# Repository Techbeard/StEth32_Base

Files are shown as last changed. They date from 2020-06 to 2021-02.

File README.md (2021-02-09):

# StEth32_Base

Das STEth32_Base ist ein auf STM32 Basiendes Ethernet Board. Es ist eine Fortführung des schon bestehenden [StEth32](https://github.com/Techbeard/StEth32). Dieses mal ist das Board allerdings darauf optimiert/ausgelegt in einm [Alu-Gehäuse](https://www.reichelt.de/profilgehaeuse-1455-l-120-x-103-x-31-mm-silber-1455l1202-p221363.html?&nbc=1)  eingesetzt zu werden. 

Um das Board möglichst vielseitig nutzen zu können sind auf dem Base Board alle unverwendeten Pins auf die Hinteren Vier Buchsenleisten geführt, wodurch Sie auf einem Erweiterungsboard für alles mögliche eingestezt werden können.

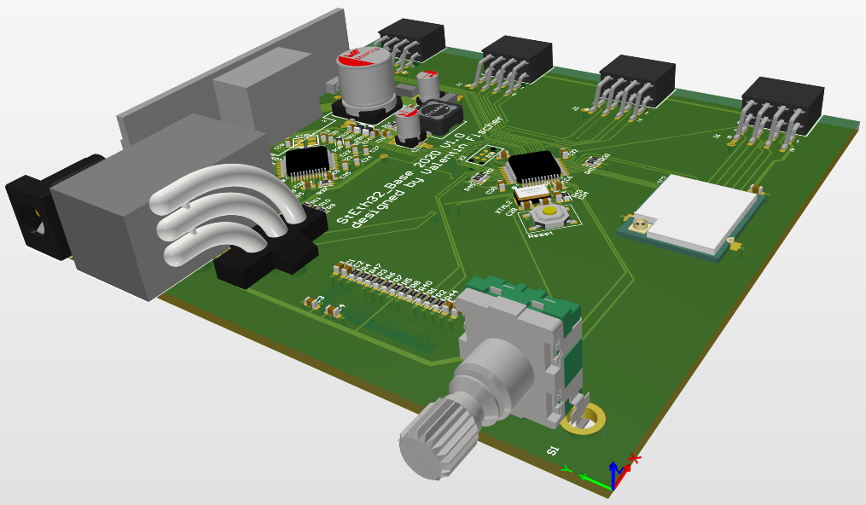
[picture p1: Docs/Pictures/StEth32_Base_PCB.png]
StEth32 Base Board


## Fetures auf dem Base Board

Eingangsspannung: 5 - 28 V

- [OLED](https://lcsc.com/product-detail/OLED-Displays-Modules_Shenzhen-Allvision-Tech-QG-2864KLBLG01_C90547.html)
- [Drehencoder](https://www.conrad.de/de/p/alps-stec11b02-encoder-5-v-dc-0-01-a-360-1-700696.html)
- Ethernet mit W5500
- 5.5x2.1 Hohlbuchse zur Stromversorgung
- POE Module zur Stromversorgung
- Footprint für [NRF24](https://lcsc.com/product-detail/Wireless-Modules_Chengdu-Ebyte-Elec-Tech-E01-ML01SP4_C97340.html)
- 2x Status LED

## Pinout

J3                                                                
| STM32 | Function | Pin | Pin | Function  | STM32 |
| :-----| :--- | :----- | :----- | :--- | :---- |
| | Vcc | **1**  | **2**  | Vcc | |  
| | TX3 | **3**  | **4**  | RX3 | | 
| | RX2 | **5**  | **6**  | TX2 | | 
| | TX1 | **7**  | **8**  | RX1 | |

J4
| STM32 | Function | Pin | Pin | Function  | STM32 |
| :-----| :--- | :----- | :----- | :--- | :---- |
| | SCL | **1**  | **2**  | SDA | |  
|  PB3  | | **3**  | **4**  |  USB/CAN  | PA12 | 
| | | **5**  | **6**  | | PB4 | 
| | 3,3V | **7**  | **8**  | GND | |

J5                                                          
| STM32 | Function | Pin | Pin | Function  | STM32 |
| :-----| :--- | :----- | :----- | :--- | :---- |
| | 3,3V | **1**  | **2**  | | PB8 |  
| PA15  | | **3**  | **4**  | RX1 | PB9 | 
| PB5 | | **5**  | **6**  | Reset | NRST | 
| | | **7**  | **8**  | GND | GND |

J6
| STM32 | Function | Pin | Pin | Function  | STM32 |
| :-----| :--- | :----- | :----- | :--- | :---- |
| | 3,3V | **1**  | **2**  | |  PA8 |  
| | CS | **3**  | **4**  | | PB1 | 
| | SCK | **5**  | **6**  | MOSI | PA3 | 
| | MISO | **7**  | **8**  | GND | |

## Intern verwendete Pins

### Ethernet SPI

Der Ethernet Chip W5500 hängt auf dem SPI2 des STM32:

    MOSI => PB15
    MISO => PB14
    SCK  => PB13
    CS   => PB12
    INT  => PA8

### Serial RS485

Der MAX485 hängt an den Pins für den Serial1 des STM32
 
    RX => PB11
    TX => PB10
    EN => PB1

### Staus Led

    LED => PC13 LOW aktiv

### MOSFET Ausgänge

    T1 => PB3
    T2 => PA15
    T3 => PB5
    T4 => PB4

# Einsatzzwecke / Erweiterungsboards

## Artnet2DMX

Das erste Erweiterungsboard verwandelt das Baseboard in einen Artnet to DMX Converter zu verwandeln. Es Werden die 3 Serielen Schnittstellen des STM32 zu RS4
85 gewandelt und über 3 XLR Buchsen ausgegeben. 

Die dazugehörige Software findest man hier:

https://github.com/LeoDJ/StEth32_Artnet2DMX

|||
|:--:|:--:|
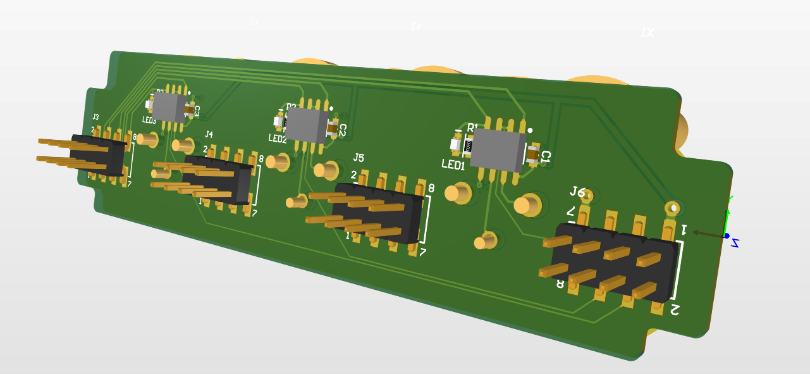
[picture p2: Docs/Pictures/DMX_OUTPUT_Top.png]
Rückseite des Erweiterungsboards
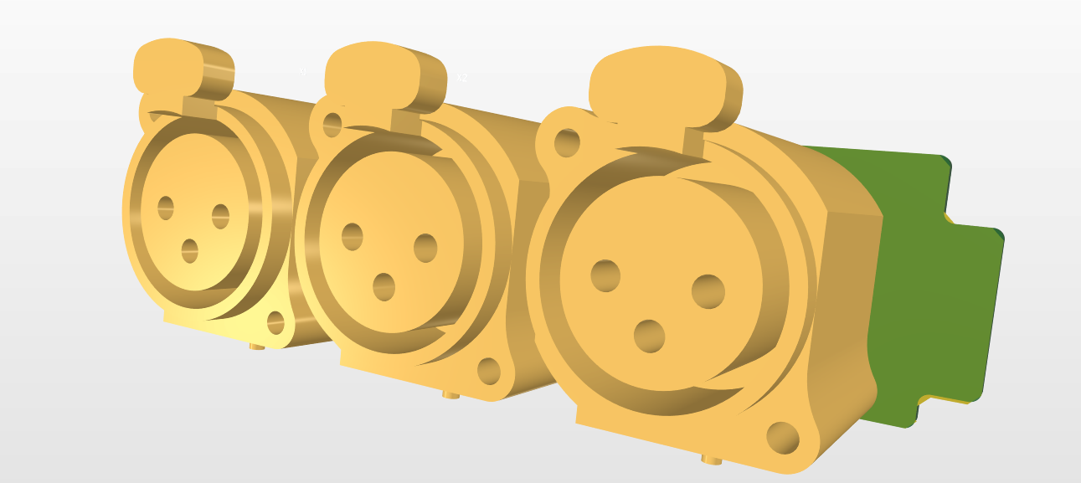
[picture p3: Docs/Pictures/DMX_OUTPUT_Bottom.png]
Vorderseite des Erweiterungsboards
|  | |
|*Rückseite des Erweiterungsboards*|*Vorderseite des Erweiterungsboards*|
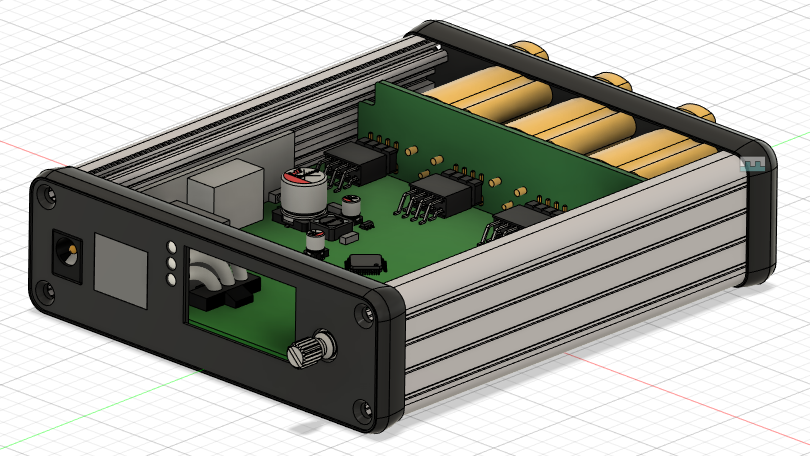
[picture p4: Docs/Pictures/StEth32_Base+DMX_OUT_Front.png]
StEth32
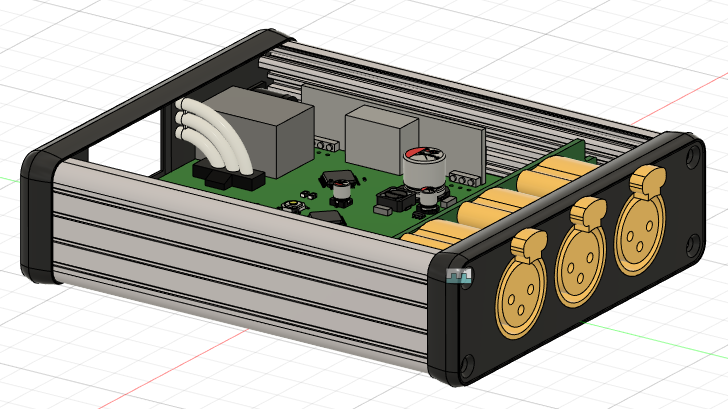
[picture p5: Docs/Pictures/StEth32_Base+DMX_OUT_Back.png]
StEth32
|  | |
|*StEth32_Base + DMX Erweiterung im Gehäuse*|*StEth32_Base + DMX Erweiterung im Gehäuse*|

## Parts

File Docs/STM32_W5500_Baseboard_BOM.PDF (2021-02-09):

Comment | Description | Designator | Footprint | LibRef | Quantity
Lightguid_3LED | Lichtleiter 3Dach 90° | | LightGuid3 | Lightguid_3LED | 1
865080457015 | WCAP-ASLI Aluminu2 | | WC AP-ASLI_10x10.5 | 865 0804 57015 | 1
2.2µF | CAP CER 2.2UF 16V XC1, C2, C3, C4, C5 | | SMD-0603C | GRM188C81C225KA12 | 5
10µF | CAP CER 10UF 6.3V | C6 | SMD-0603C | GRM185R60J106ME15 | 1
0.10µF | CAP CER 0.1UF 16V | C7, C8, C10, C16, C2S MD-0 603C | | G CM1 88R7 1C104 KA37 | 14
0.022µF | CAP CER 0.022UF 50 C9 | | SMD-0603C | GCJ188R71H223KA01 | 1
865080140001 | WCAP-ASLI AluminuC11, C37 | | WC AP-ASLI_4x5.5 | 86 5080 140001 | 2
22µF | CAP CER 22UF 4V X5RC12, C14 | | SMD-0603C | ZRB186R60G226ME11 | 2
6800pF | CAP CER 6800PF 50V C13, C17 | | SMD-0603C | GCM188R71H682KA37 | 2
22nF | CAP CER 0.022UF 10C 15 | | SMD-0603C | GCM188R72A223KA37 | 1
22pF | CAP CER 0.022UF 10C 18, C19 | | SMD-0603C | GCM188R72A223KA37 | 2
22uF | CAP CER 0.1UF 16V | C20 | SMD-0603C | GCM188R71C104KA37 | 1
10nF | CAP CER 0.1UF 16V | C21 | SMD-0603C | GCJ188R71C104KA01 | 1
4.7uF | CAP CER 0.1UF 16V | C27 | SMD-0603C | GCJ188R71C104KA01 | 1
20pF | CAP CER 0.1UF 16V | C28, C29 | SMD-0603C | GCM188R71C104KA37 | 2
865080243007 | WCAP-ASLI AluminuC35 | | WC AP-ASLI_6.3x5.5 | 865 0802 43007 | 1
SS34 | Shottkydiode | D1, D4 | B240A | B240A | 2
BZM55 | | D3 | SMD-0603-RES | BZM55 | 1
600Ohm, 0.2A | WE-CBF SMT EMI SuFB1, FB2 | | W E-CBF_0 805_High S742792042 | | 2
UG-2864KSWLG01 | OLED 1,3" 128x64 | IC1 | UG-2864KSWLG01 | UG-2864KSWLG01 | 1
NRF24 | | IC2 | ML01SP4 | NRF24 | 1
ACT4088 | | IC3 | SOT23-6 | ACT4088 | 1
POE_Module | | IC4 | POE_Module | POE_Module | 1
W5500 | | IC5 | LQFP-48 | W5500 | 1
STM32F072C8U6 | | IC6 | LQFP-48 | STM32F072C8U6 | 1
694106301002 | DC Power Jack ConnJ1 | | 69410630100 2 | 694106301002 | 1
610108249221 | WR-PHD SocketHeadJ3, J4, J5 , J6 | | 61 010824922 1 | 610108249221 | 4
4.7uH, 2.32A | WE-PD SMT Power InL1 | | WE -PD_7332 | 744778004 | 1
150060SS75000 | SMD mono-color ChiLED1, LED2, LED3 | | 0603_A | 150060SS75000 | 3
4.7k | RES SMD 4.7K OHM | R1, R2, R46 | SMD-0603-RES | ERJ-PA3F4701V | 3
10k | RES SMD 10K OHM 1R3, R4, R5, R6, R7, R8S MD- 0603- RES | | | ERJ- 3EKF 1002 V, ER J- | 27
1k | RES SMD 1K OHM 1%R9, R11 | | SMD-0603-RES | ERJ-3EKF1001V | 2
330 | RES SMD 330 OHM 1R10, R16, R19 | | SMD-0603-RES | ERJ-3EKF3300V | 3
100k | RES SMD 4.7K OHM | R12 | SMD-0603-RES | ERJ-3EKF4701V | 1
3k3 | RES SMD 1K OHM 1%R14 | | SMD-0603-RES | ERJ-3EKF1001V | 1
49.9 | RES SMD 49.9 OHM 1R15, R18, R20, R21 | | SMD-0603-RES | ERJ-3EKF49R9V | 4
10 | RES SMD 330 OHM 1R17 | | SMD-0603-RES | ERJ-3EKF3300V | 1
1M | RES SMD 1M OHM 5%R36 | | SMD-0402-RES | ERJ-2GEJ105X | 1
12k4 | RES SMD 12,4 KOHMR37 | | SMD-0603-RES | ERJ-3BQF1R1V | 1
390k | RES SMD 390K OHM R44 | | SMD-0603-RES | ERJ-3EKF3903V | 1
290VAA5F201B2 | Switch | S1 | EC11B | 290VAA5F201B2 | 1
Button | 6.1x3.7x2.5mm | S3 | Button5050 | Button | 1
AO3401 | AO3401MOSFET 30VT1 | | SOT23 | AO3401 | 1
HR971169C | | X1 | HR971169C | HR971169C | 1
ICSP | | X2 | TC2030-MCP-NL | ICSP | 1
Crystal | | XTAL1 | 3225 | 3225 | 1
Crystal 5032 | | XTAL2 | 5032 | 5032 | 1

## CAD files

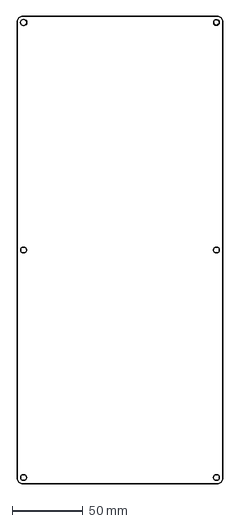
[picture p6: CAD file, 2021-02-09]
Docs/LaserAkkucase.dxf
145.0 x 330.0 mm

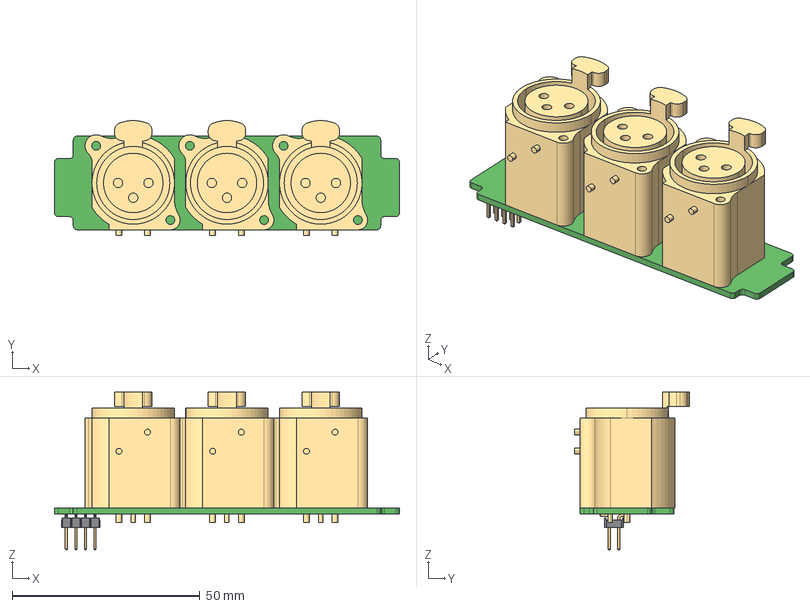
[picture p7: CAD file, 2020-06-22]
Output_Boards/StEth32_Base_XLR_Output.step
92.0 x 30.6 x 42.1 mm
3-d-nc3faav1 x 3
6100xx21121_PIN x 8

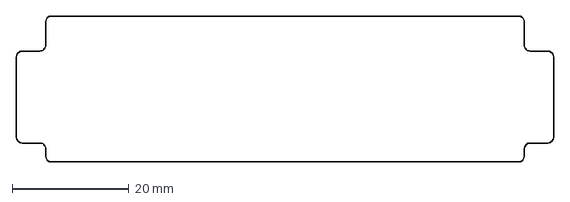
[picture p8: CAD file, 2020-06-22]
Output_Boards/StEth32_Base_output PCB Umriss.dxf
92.0 x 25.0 mm

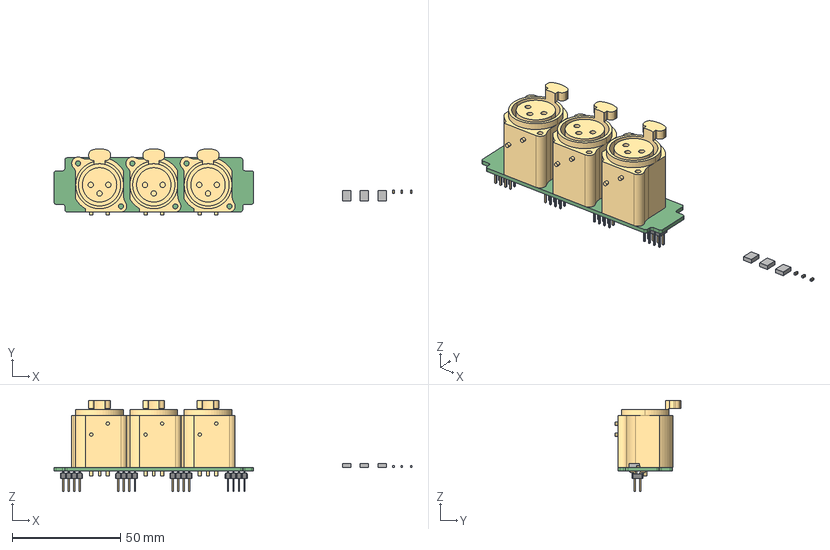
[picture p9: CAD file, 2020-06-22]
Output_Boards/StEth32_Base_XLR_Output_WITH$cONNNECTOREN.step
165.0 x 30.6 x 42.1 mm
6100xx21121_PIN x 32
Extruded x 3
capacitor_0603 x 3
3-d-nc3faav1 x 3

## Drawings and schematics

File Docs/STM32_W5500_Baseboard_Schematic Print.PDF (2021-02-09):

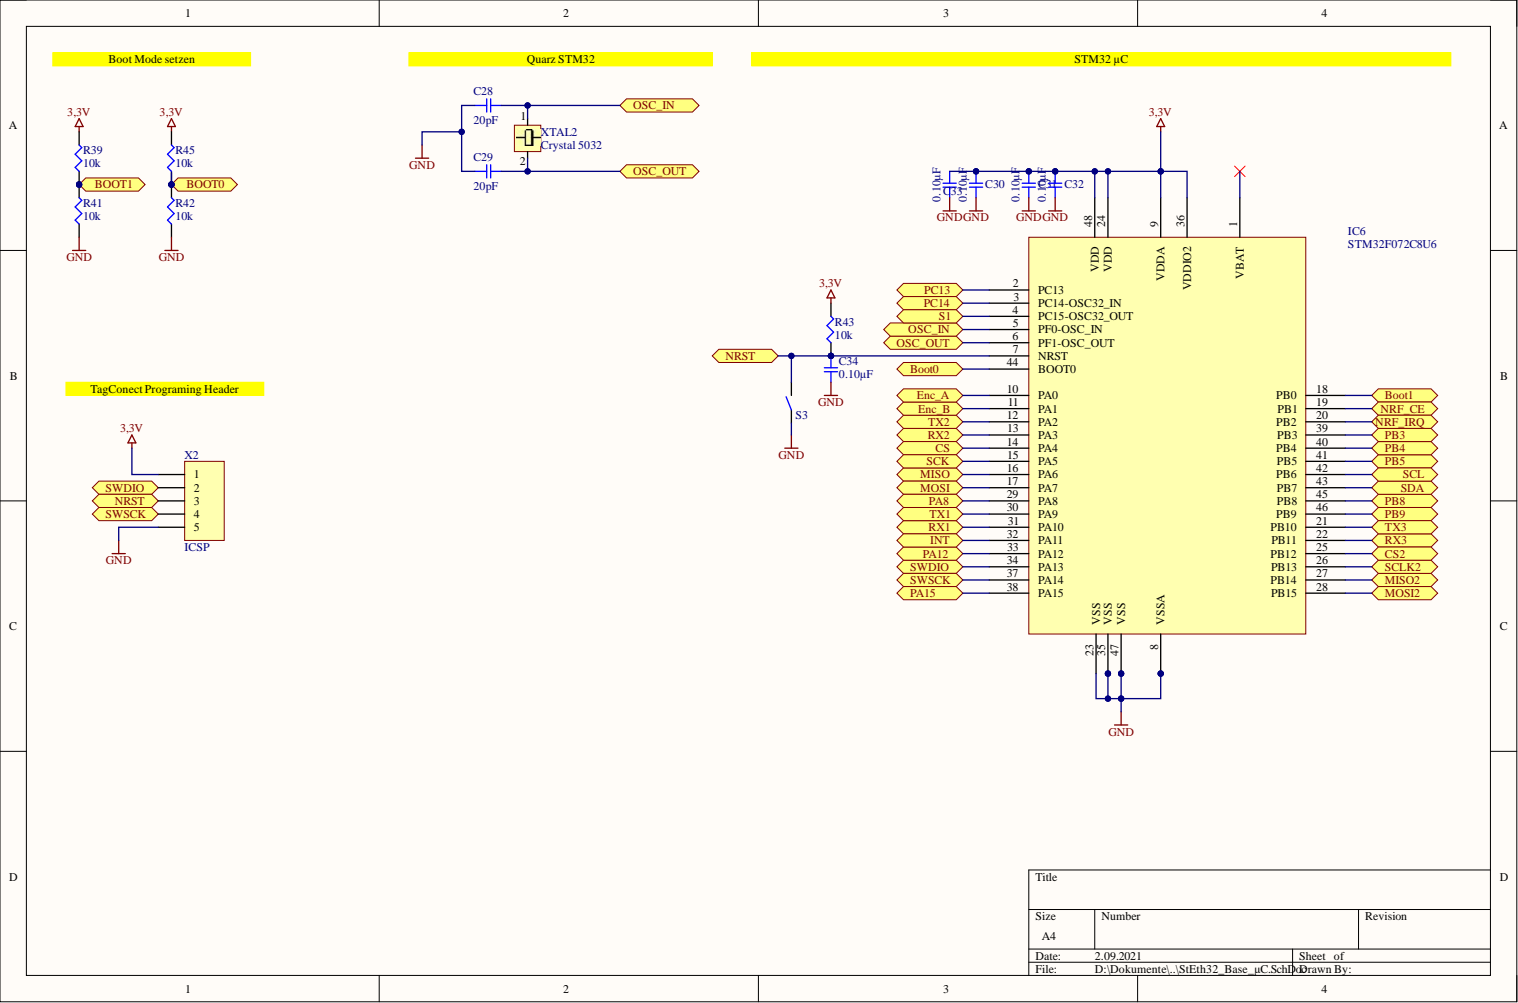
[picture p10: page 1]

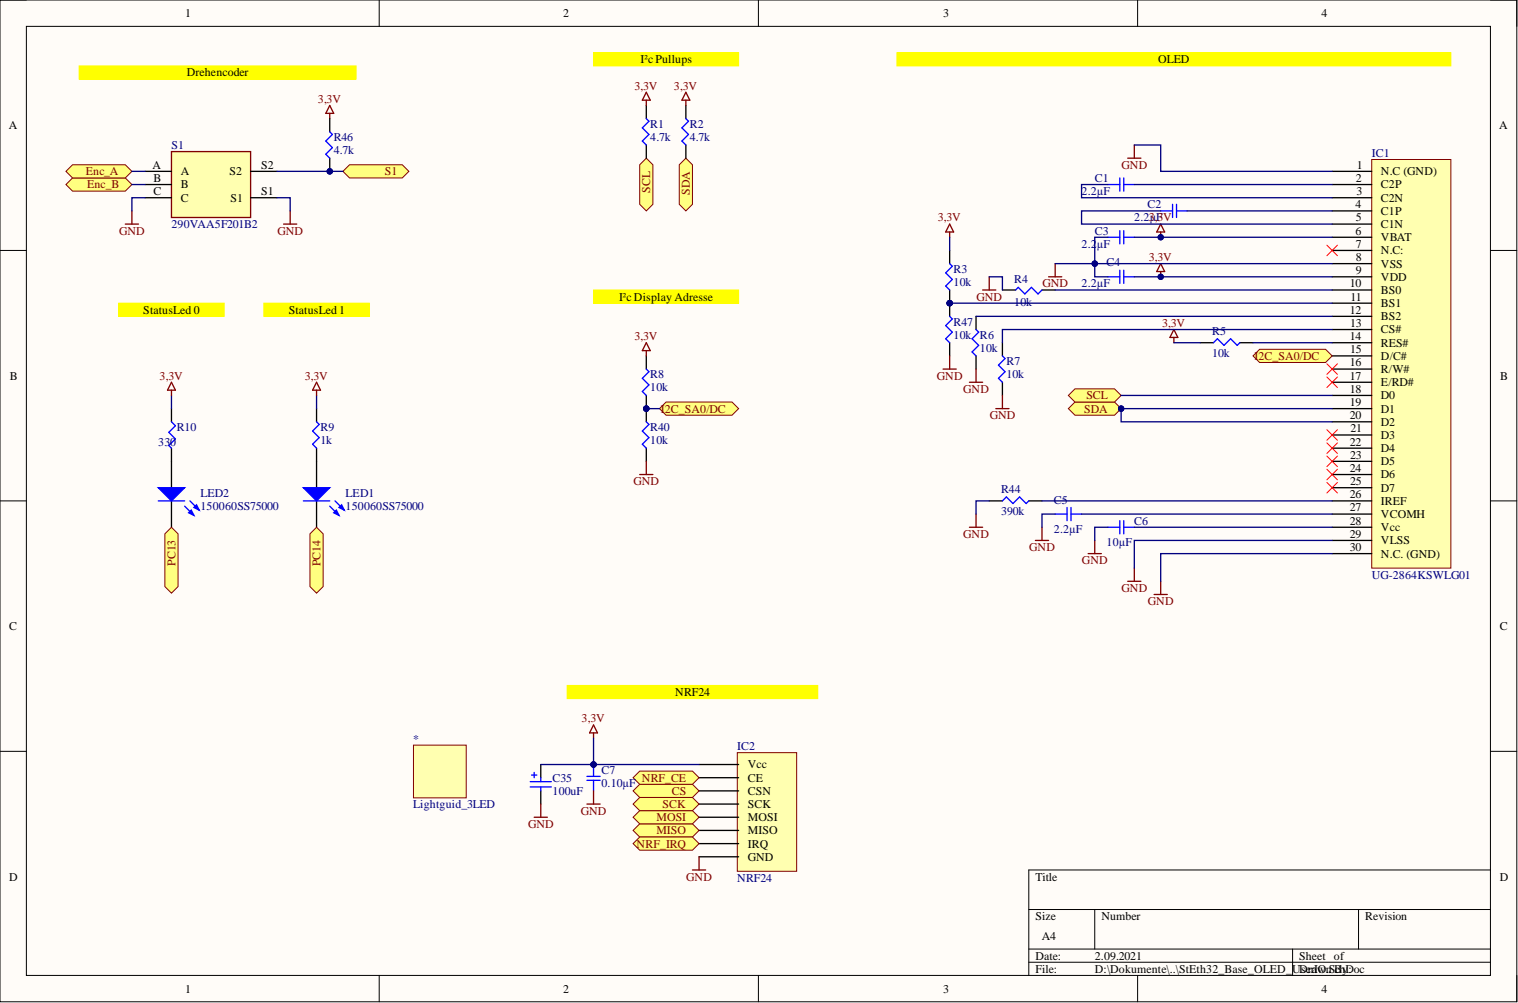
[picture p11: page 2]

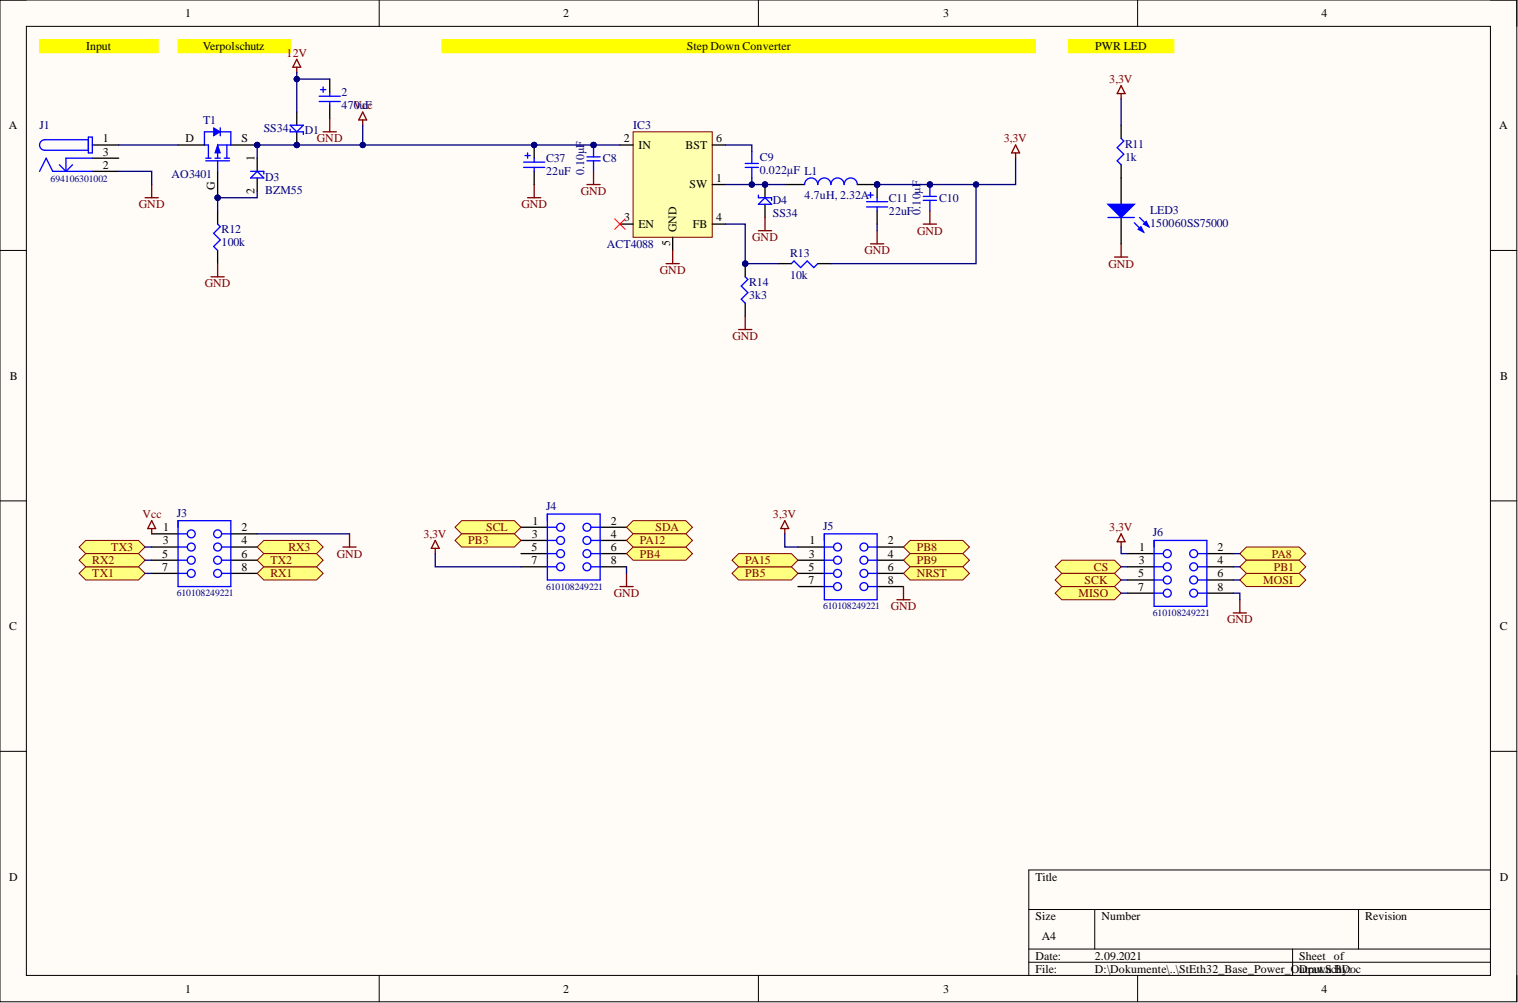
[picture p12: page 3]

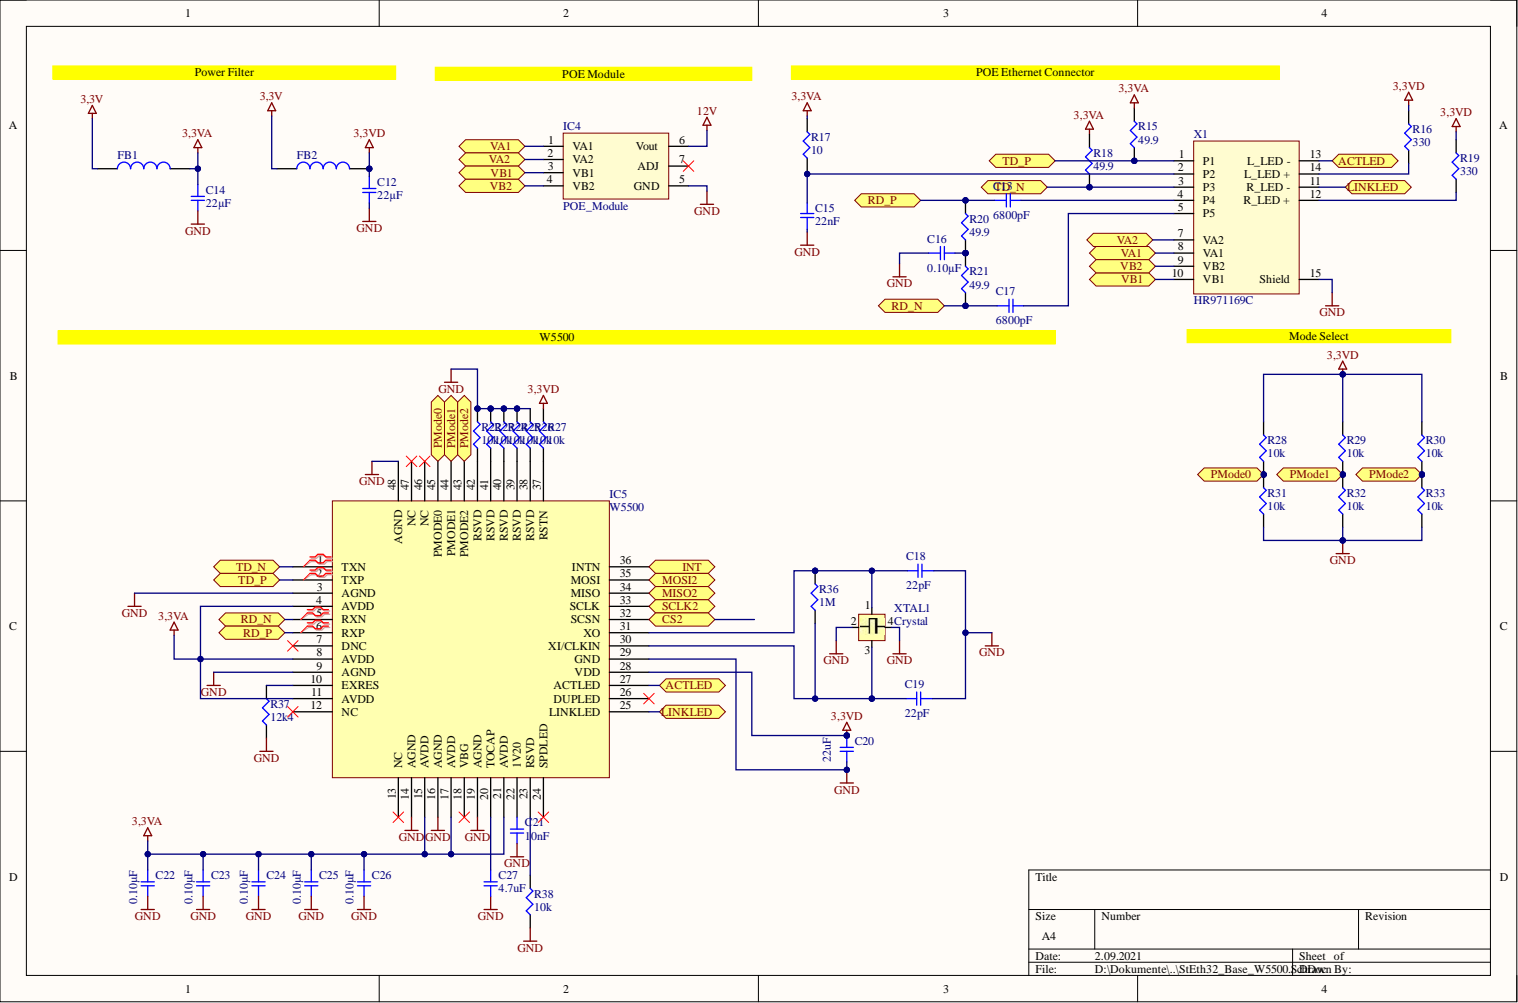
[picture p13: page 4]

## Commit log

2020-06-22 initial Push
    [STM32_W5500_Baseboard.PrjPcb, StEth32_Base_OLED_UserIO.SchDoc, StEth32_Base_Power_Output.SchDoc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]
2020-06-30 edit readme
    [STM32_W5500_Baseboard.PrjPcb, StEth32_Base_Power_Output.SchDoc, StEth32_Base_XLR_Output.PcbDoc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]
2021-02-09 add pdf
    [LaserAkkucase.dxf, STM32_W5500_Baseboard.PrjPcb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]
